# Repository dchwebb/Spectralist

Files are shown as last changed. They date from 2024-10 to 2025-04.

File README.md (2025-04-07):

# Spectralist

## Overview

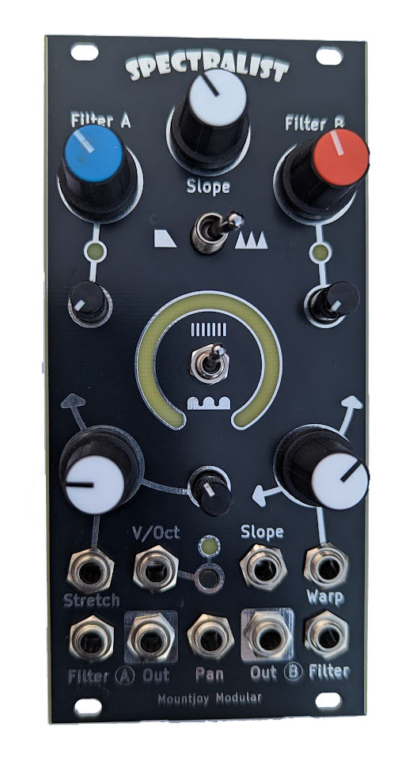
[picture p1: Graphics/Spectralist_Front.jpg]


Spectralist is an additive oscillator for Eurorack modular synthesisers. Up to 300 harmonics are output over two separate Odd and Even channels with a 'filter' offering a range of options for sculpting the harmonic spectrum of the output signals.

There are two harmonic modes - individual harmonics and sinusoidal waves of harmonics. In individual harmonic mode the spread controls adjust the spacing of the harmonics and the warp control either progressively bunches up or spreads out the harmonics. In the sinusoidal mode the spread controls increase the frequency of the 'waves' of harmonics.

The filter can be selected as a low pass filter with continuously adjustable slope or as a comb filter with adjustable tooth width and spread. In the comb filter mode the channel filter controls set the width between teeth and the slope sets the rise and fall times of the teeth. The individual channel filters controls can be adjusted with potentiometers or by CV with with trimmers to attenuate.

The pan CV input allows each channel to be smoothly panned between the two outputs. This can be used to mix the signals together in a mono setup, or used to dynamically shift the harmonics in the stereo field.

In the centre of the module is a ring of LEDs that give a visual representation of the harmonic spread and warp settings.

The module was designed in conjunction with musician Tal Shoshani who produced the following demonstration video:

IMAGE ALT TEXT HERE (https://www.youtube.com/watch?v=pN7oqAjkgNs)

## Technical

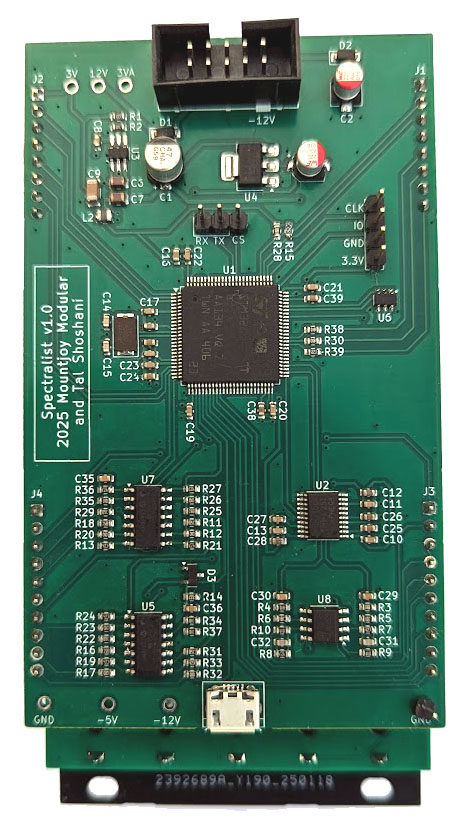
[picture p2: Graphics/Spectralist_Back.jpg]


The module is based around an STM32H723VGT microcontroller, clocked at 400MHz. A TI PCM5100APW 32 bit audio DAC is used for the two channel outputs.

A TL072 dual op-amps is used to amplify and filter the DAC output (and/or phase invert) the outputs from 3V to 9V peak-to-peak at maximum. Input CV signals are conditioned by MCP6004 op-amps.

A USB B micro port is available at the rear of the unit for software updgrades and configuration via a serial connection.

The animated 25 LED display is driven over I2C by a PCA9956B LED Driver and the SMD LEDs sit on a daughter board raising them to the level of the front panel.

[Components schematic](Hardware/Spectralist_Components.pdf)

[LED daughterboard schematic](Hardware/Spectralist_LED_Daughterboard.pdf)

[Controls schematic](Hardware/Spectralist_Controls.pdf)

## Power

Analog power is supplied via a 3.3V LDO regulator and digital power uses a TPS561201 switching power supply.

- +12V current draw: 139 mA
- -12V Current draw: 7 mA

## Errata

Panel Errata: Mode switch hole too large for subminiature switch
Filter type switch hole just too narrow
Harm_Warp_pot and Harm_Stretch_Pot wrong way round (fixed 1.1)

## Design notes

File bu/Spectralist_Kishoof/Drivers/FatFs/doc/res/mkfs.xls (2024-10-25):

Drive Size [sector] | ANY+SFD au = 0 |  |  | ANY+SFD au = 4096 |  |  | EXFAT+FAT32+SFD au = 0 |  |  | EXFAT+SFD au = 0 |  |  | FAT32+FAT+SFD au = 0 |  |  | FAT32+SFD au = 0 |  |  | FAT+SFD au = 0
 | Type | csize | n_clust | Type | csize | n_clust | Type | csize | n_clust | Type | csize | n_clust | Type | csize | n_clust | Type | csize | n_clust | Type | csize | n_clust
1024 | FAT12 | 1 | 987 | FAT12 | 8 | 123 |  |  |  |  |  |  | FAT12 | 1 | 987 |  |  |  | FAT12 | 1 | 987
1025 | FAT12 | 1 | 988 | FAT12 | 8 | 123 |  |  |  |  |  |  | FAT12 | 1 | 988 |  |  |  | FAT12 | 1 | 988
1026 | FAT12 | 1 | 989 | FAT12 | 8 | 124 |  |  |  |  |  |  | FAT12 | 1 | 989 |  |  |  | FAT12 | 1 | 989
1027 | FAT12 | 1 | 990 | FAT12 | 8 | 124 |  |  |  |  |  |  | FAT12 | 1 | 990 |  |  |  | FAT12 | 1 | 990
1028 | FAT12 | 1 | 991 | FAT12 | 8 | 124 |  |  |  |  |  |  | FAT12 | 1 | 991 |  |  |  | FAT12 | 1 | 991
1029 | FAT12 | 1 | 992 | FAT12 | 8 | 124 |  |  |  |  |  |  | FAT12 | 1 | 992 |  |  |  | FAT12 | 1 | 992
1030 | FAT12 | 1 | 993 | FAT12 | 8 | 124 |  |  |  |  |  |  | FAT12 | 1 | 993 |  |  |  | FAT12 | 1 | 993
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

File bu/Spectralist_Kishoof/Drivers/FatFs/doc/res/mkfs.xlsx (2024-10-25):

sz_vol [sector] | .fmt = ANY .au_size = 0 |  |  | .fmt = ANY .au_size = 4096 |  |  | .fmt = EXFAT+FAT32 .au_size = 0 |  |  | .fmt = EXFAT .au_size = 0 |  |  | .fmt = FAT32+FAT .au_size = 0 |  |  | .fmt = FAT32 .au_size = 0 |  |  | .fmt = FAT .au_size = 0
 | Type | csize | n_clust | Type | csize | n_clust | Type | csize | n_clust | Type | csize | n_clust | Type | csize | n_clust | Type | csize | n_clust | Type | csize | n_clust
1024 | FAT12 | 1 | 987 | FAT12 | 8 | 123 |  |  |  |  |  |  | FAT12 | 1 | 987 |  |  |  | FAT12 | 1 | 987
1025 | FAT12 | 1 | 988 | FAT12 | 8 | 123 |  |  |  |  |  |  | FAT12 | 1 | 988 |  |  |  | FAT12 | 1 | 988
1026 | FAT12 | 1 | 989 | FAT12 | 8 | 124 |  |  |  |  |  |  | FAT12 | 1 | 989 |  |  |  | FAT12 | 1 | 989
1027 | FAT12 | 1 | 990 | FAT12 | 8 | 124 |  |  |  |  |  |  | FAT12 | 1 | 990 |  |  |  | FAT12 | 1 | 990
1028 | FAT12 | 1 | 991 | FAT12 | 8 | 124 |  |  |  |  |  |  | FAT12 | 1 | 991 |  |  |  | FAT12 | 1 | 991
1029 | FAT12 | 1 | 992 | FAT12 | 8 | 124 |  |  |  |  |  |  | FAT12 | 1 | 992 |  |  |  | FAT12 | 1 | 992
1030 | FAT12 | 1 | 993 | FAT12 | 8 | 124 |  |  |  |  |  |  | FAT12 | 1 | 993 |  |  |  | FAT12 | 1 | 993
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

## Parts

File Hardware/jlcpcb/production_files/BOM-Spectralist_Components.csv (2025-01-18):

Comment | Designator | Footprint | LCSC
8MHz 20pF | Y1 | Crystal_SMD_Abracon_ABM3-2Pin_5.0x3.2mm | C115962
PCM5100APW | U2 | TSSOP-20_4.4x6.5mm_P0.65mm | C131154
100nF | C10,C11,C13,C17,C18,C19,C20,C21,C22,C23,C27,C36,C4,C8 | C_0603_1608Metric | C14663
100pF | C31,C32 | C_0603_1608Metric | C14858
1uF | C24,C3 | C_0603_1608Metric | C15849
2.2nF | C29,C30,C35 | C_0603_1608Metric | C1604
30pF | C14,C15 | C_0603_1608Metric | C1658
4.7uF | C16 | C_0603_1608Metric | C19666
10uF | C12,C28 | C_0603_1608Metric | C19702
1k | R3,R30,R38,R39,R4 | R_0603_1608Metric | C21190
100 | R10,R9 | R_0603_1608Metric | C22775
15k | R5,R6 | R_0603_1608Metric | C22809
1k6 | R15,R28 | R_0603_1608Metric | C22843
75k | R11,R16,R18,R22,R25,R29,R31 | R_0603_1608Metric | C23242
2.2uF | C25,C26,C38,C39 | C_0603_1608Metric | C23630
100k | R12,R17,R20,R23,R26,R32,R35 | R_0603_1608Metric | C25803
10k | R2,R34,R37 | R_0603_1608Metric | C25804
47k | R13,R19,R21,R24,R27,R33,R36,R7,R8 | R_0603_1608Metric | C25819
2k2 | R14 | R_0603_1608Metric | C4190
33k | R1 | R_0603_1608Metric | C4216
10uF | C6,C7 | C_0805_2012Metric | C440198
LT1117-3.3 | U4 | SOT-223-3_TabPin2 | C6186
TL072 | U8 | SOIC-8_3.9x4.9mm_P1.27mm | C6961
STM32H723VGTx | U1 | LQFP-100_14x14mm_P0.5mm | C730142
1N5819 | D1,D2 | D_SOD-123 | C8598
47uF | C9 | C_1206_3216Metric | C96123

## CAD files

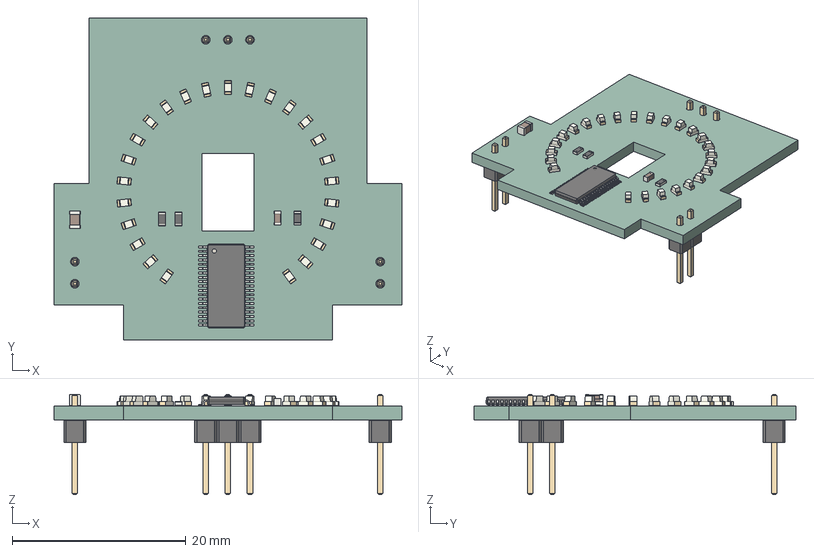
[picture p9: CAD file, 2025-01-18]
Hardware/Spectralist_LEDs.step
40.0 x 37.0 x 11.5 mm
LED_0603_1608Metric x 25
C_0805_2012Metric
R_0603_1608Metric x 3
TSSOP_38_44x97mm_P05mm
C_0603_1608Metric
PinHeader_1x02_P254mm_Vertical x 2
PinHeader_1x03_P254mm_Vertical
Spectralist_LEDs_PCB

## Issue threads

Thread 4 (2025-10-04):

Problem with firmware

tsanderakis, 2025-10-04:
Have started a Spectralist last week and for the moment I dont know which firmware is the right one.
I can talk to the STM with my Disco Board, but USB is not found, no output, just only LED No. 1 is on and thats all.
What can be wrong?
+-12V ok 5V ok 2x 3,3V ok

dchwebb, 2025-10-05:
I'm currently in Japan for a couple of weeks so have limited access to
GitHub etc. the latest firmware is here:
https://github.com/dchwebb/Spectralist/tree/main/Spectralist_H723/Debug

If you have tried that I am not sure why not working. When I am back happy
to work through some troubleshooting with you.

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

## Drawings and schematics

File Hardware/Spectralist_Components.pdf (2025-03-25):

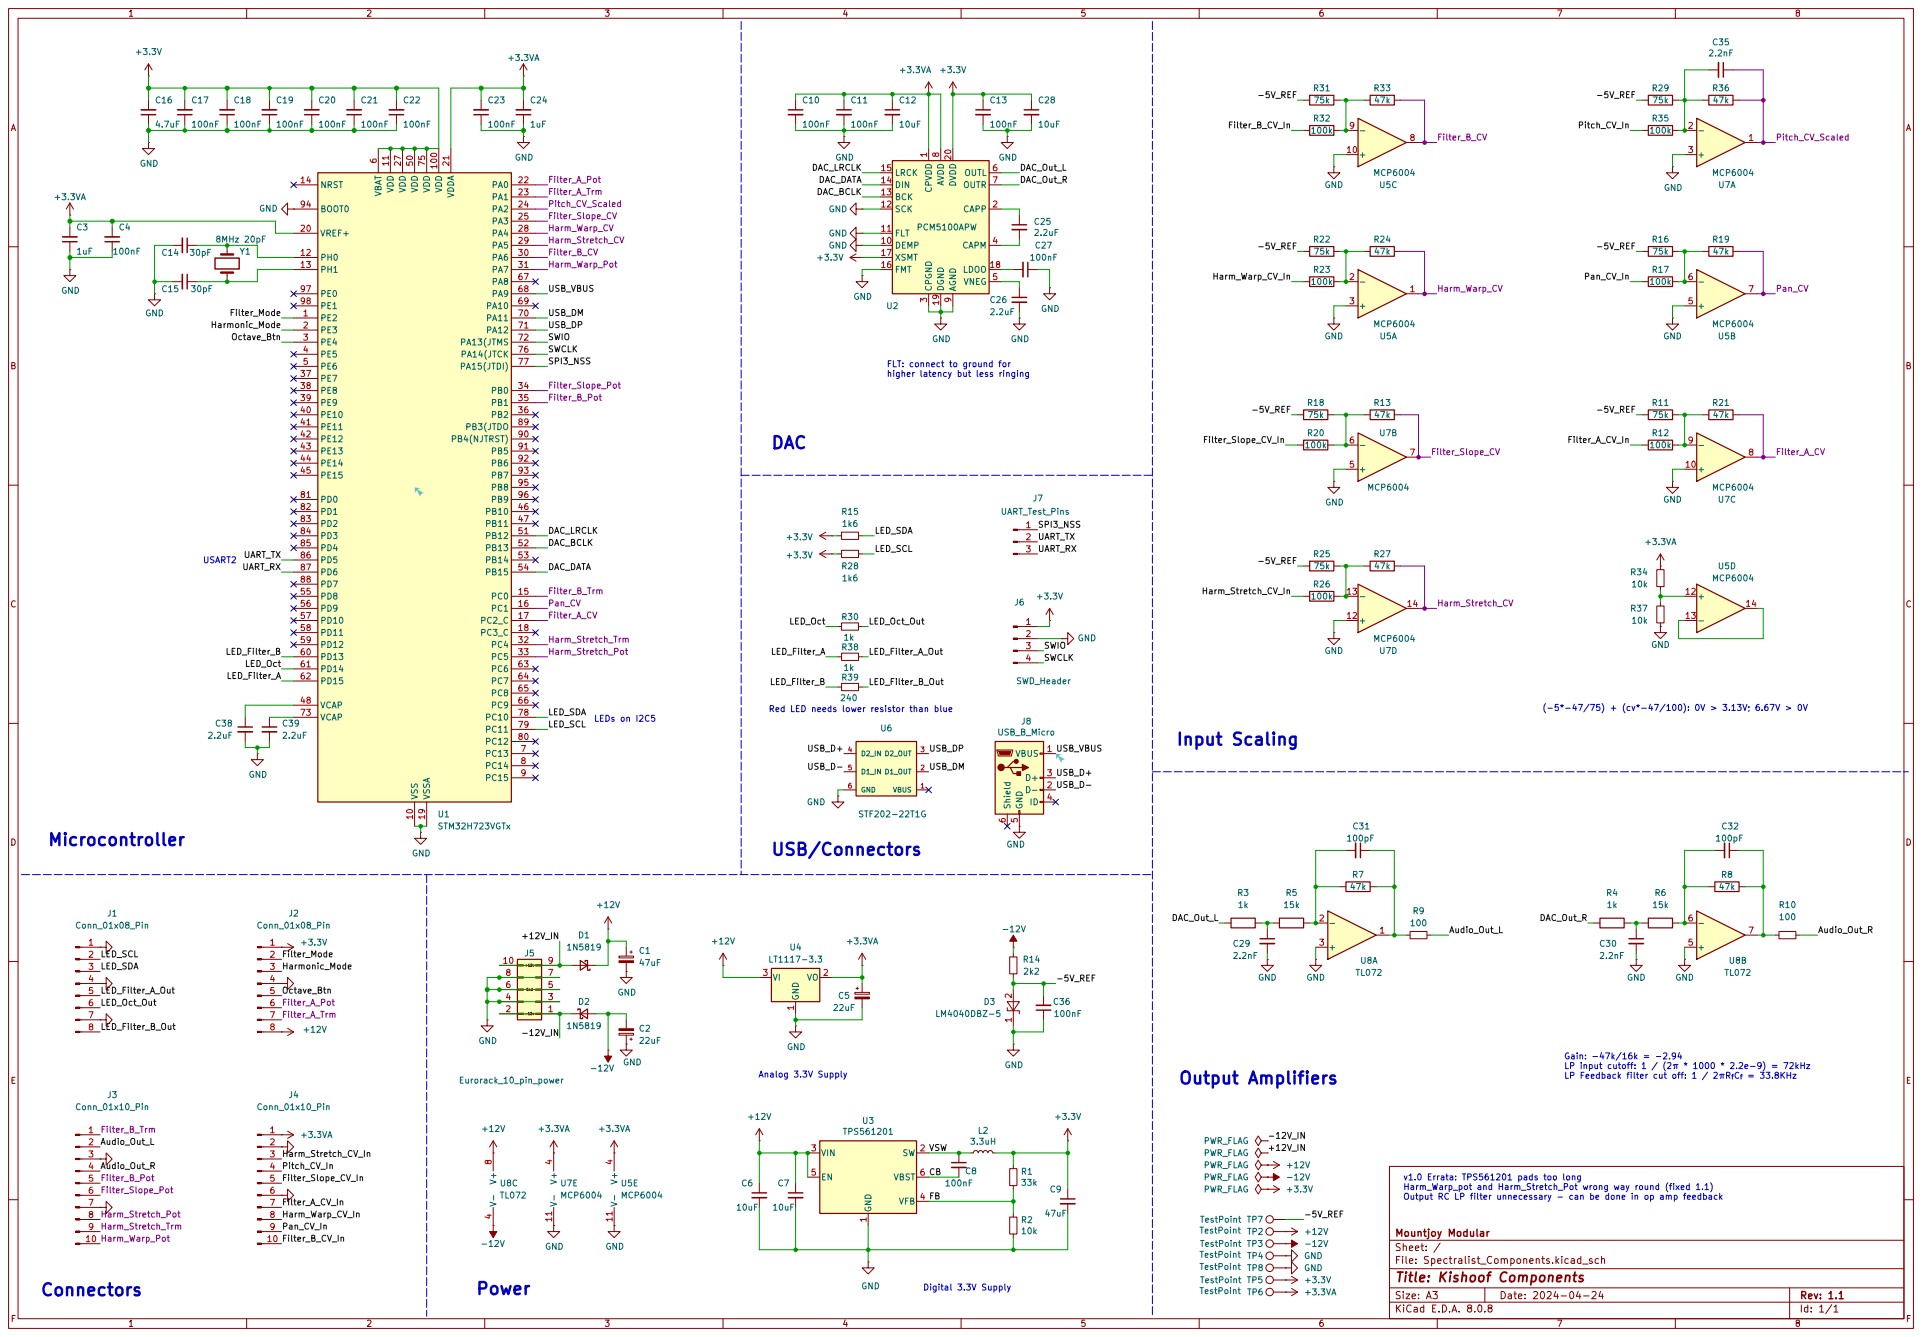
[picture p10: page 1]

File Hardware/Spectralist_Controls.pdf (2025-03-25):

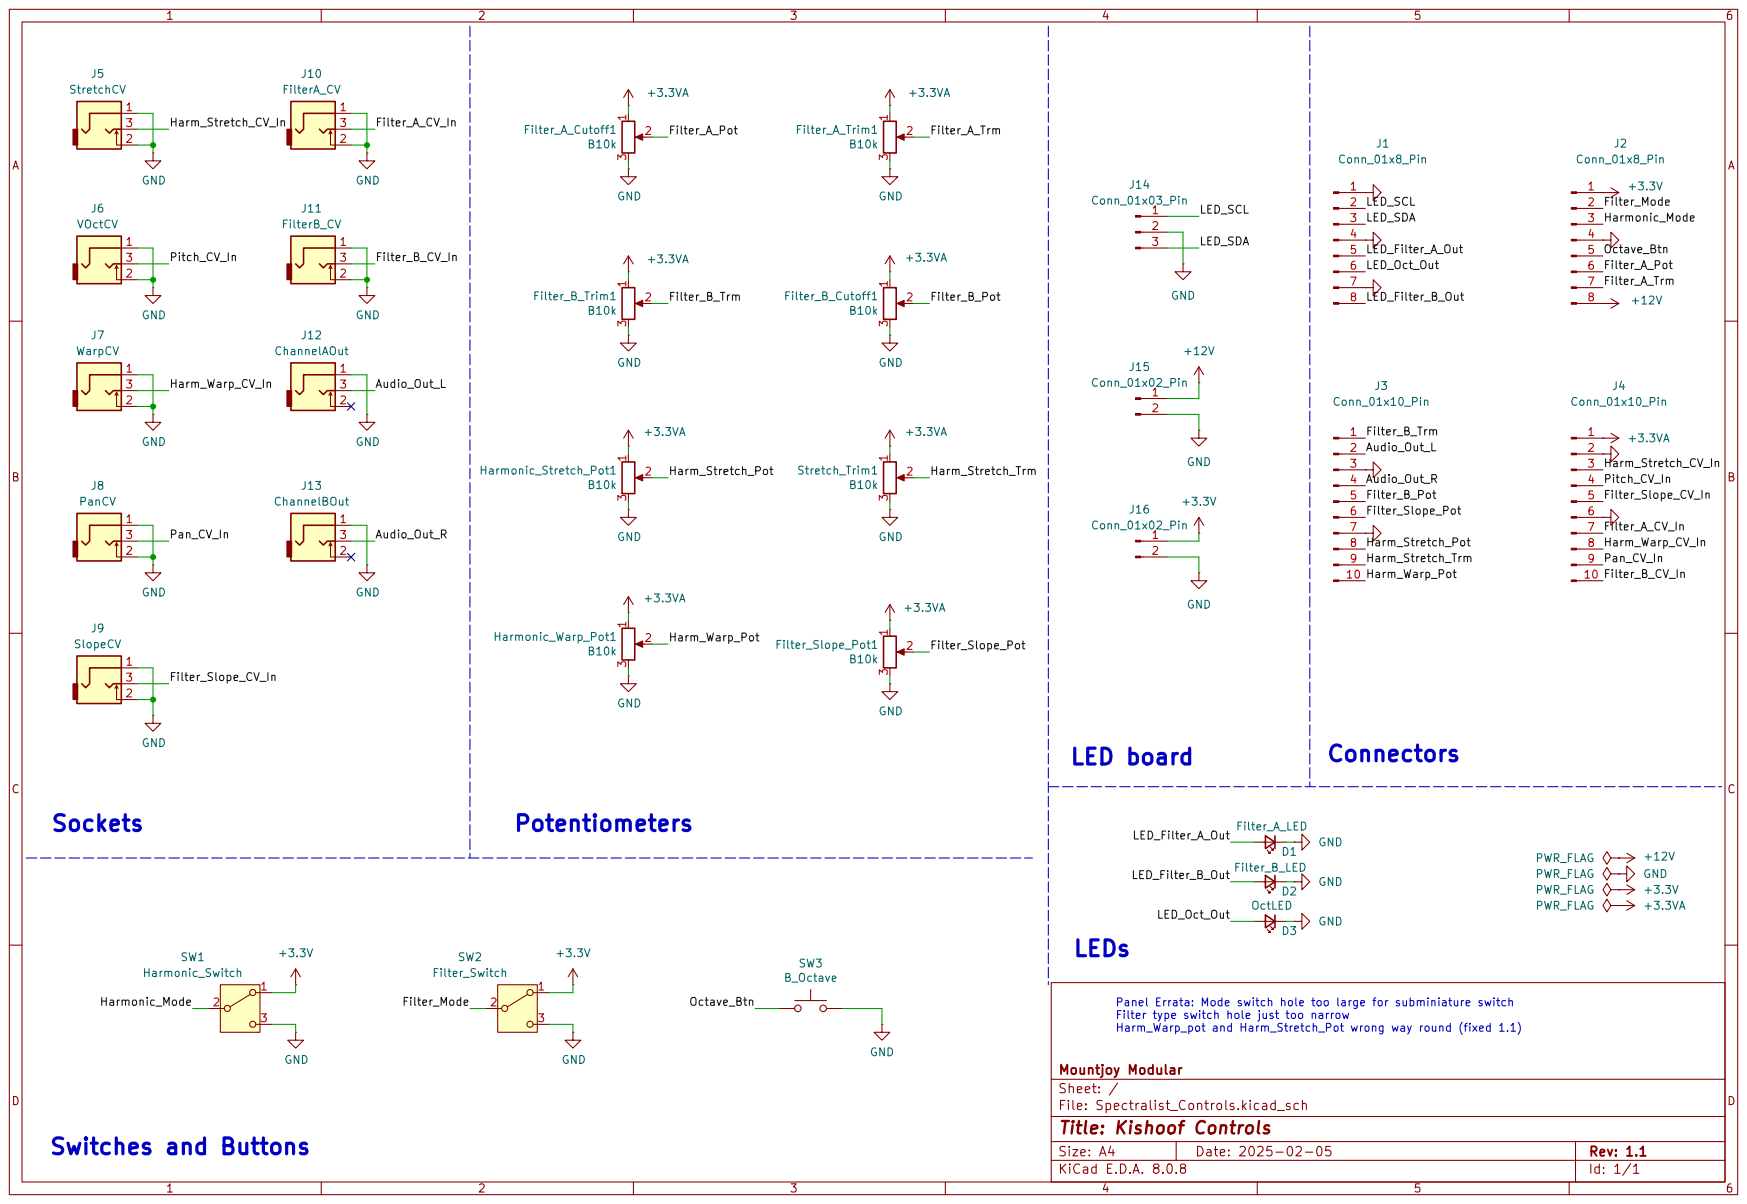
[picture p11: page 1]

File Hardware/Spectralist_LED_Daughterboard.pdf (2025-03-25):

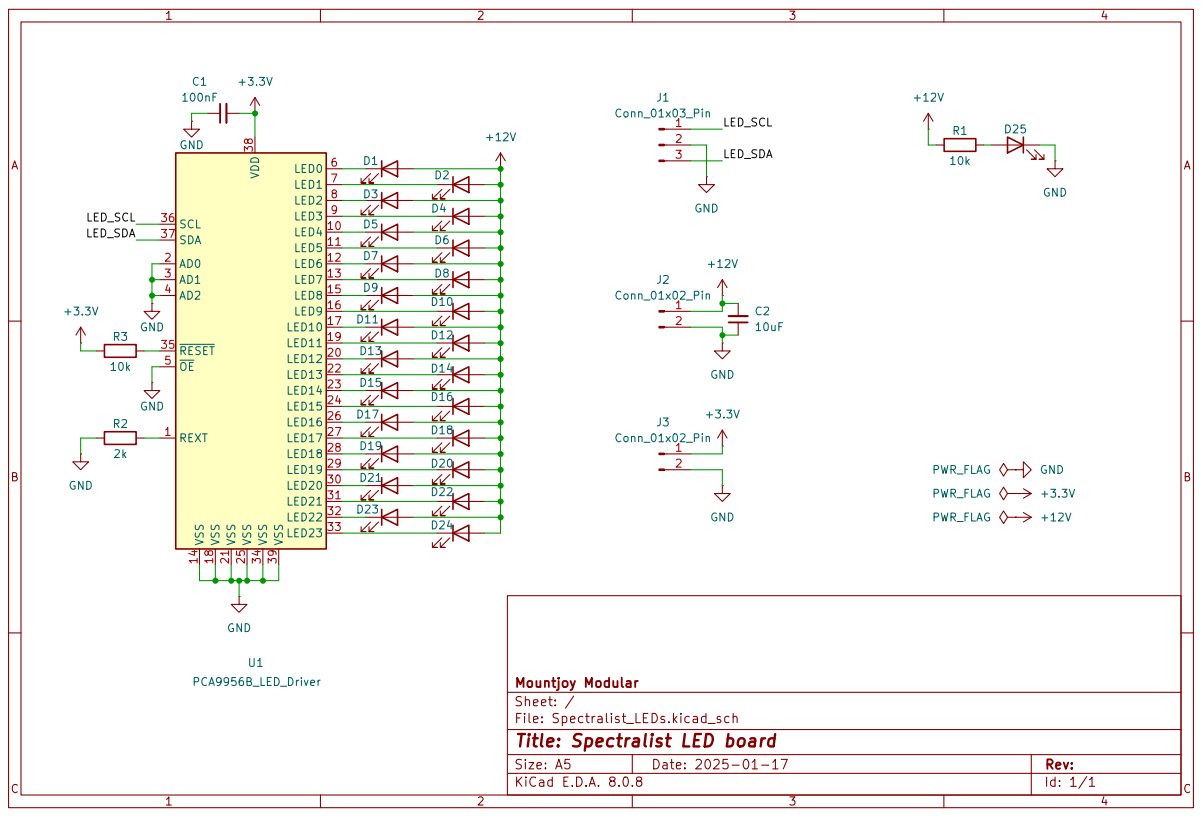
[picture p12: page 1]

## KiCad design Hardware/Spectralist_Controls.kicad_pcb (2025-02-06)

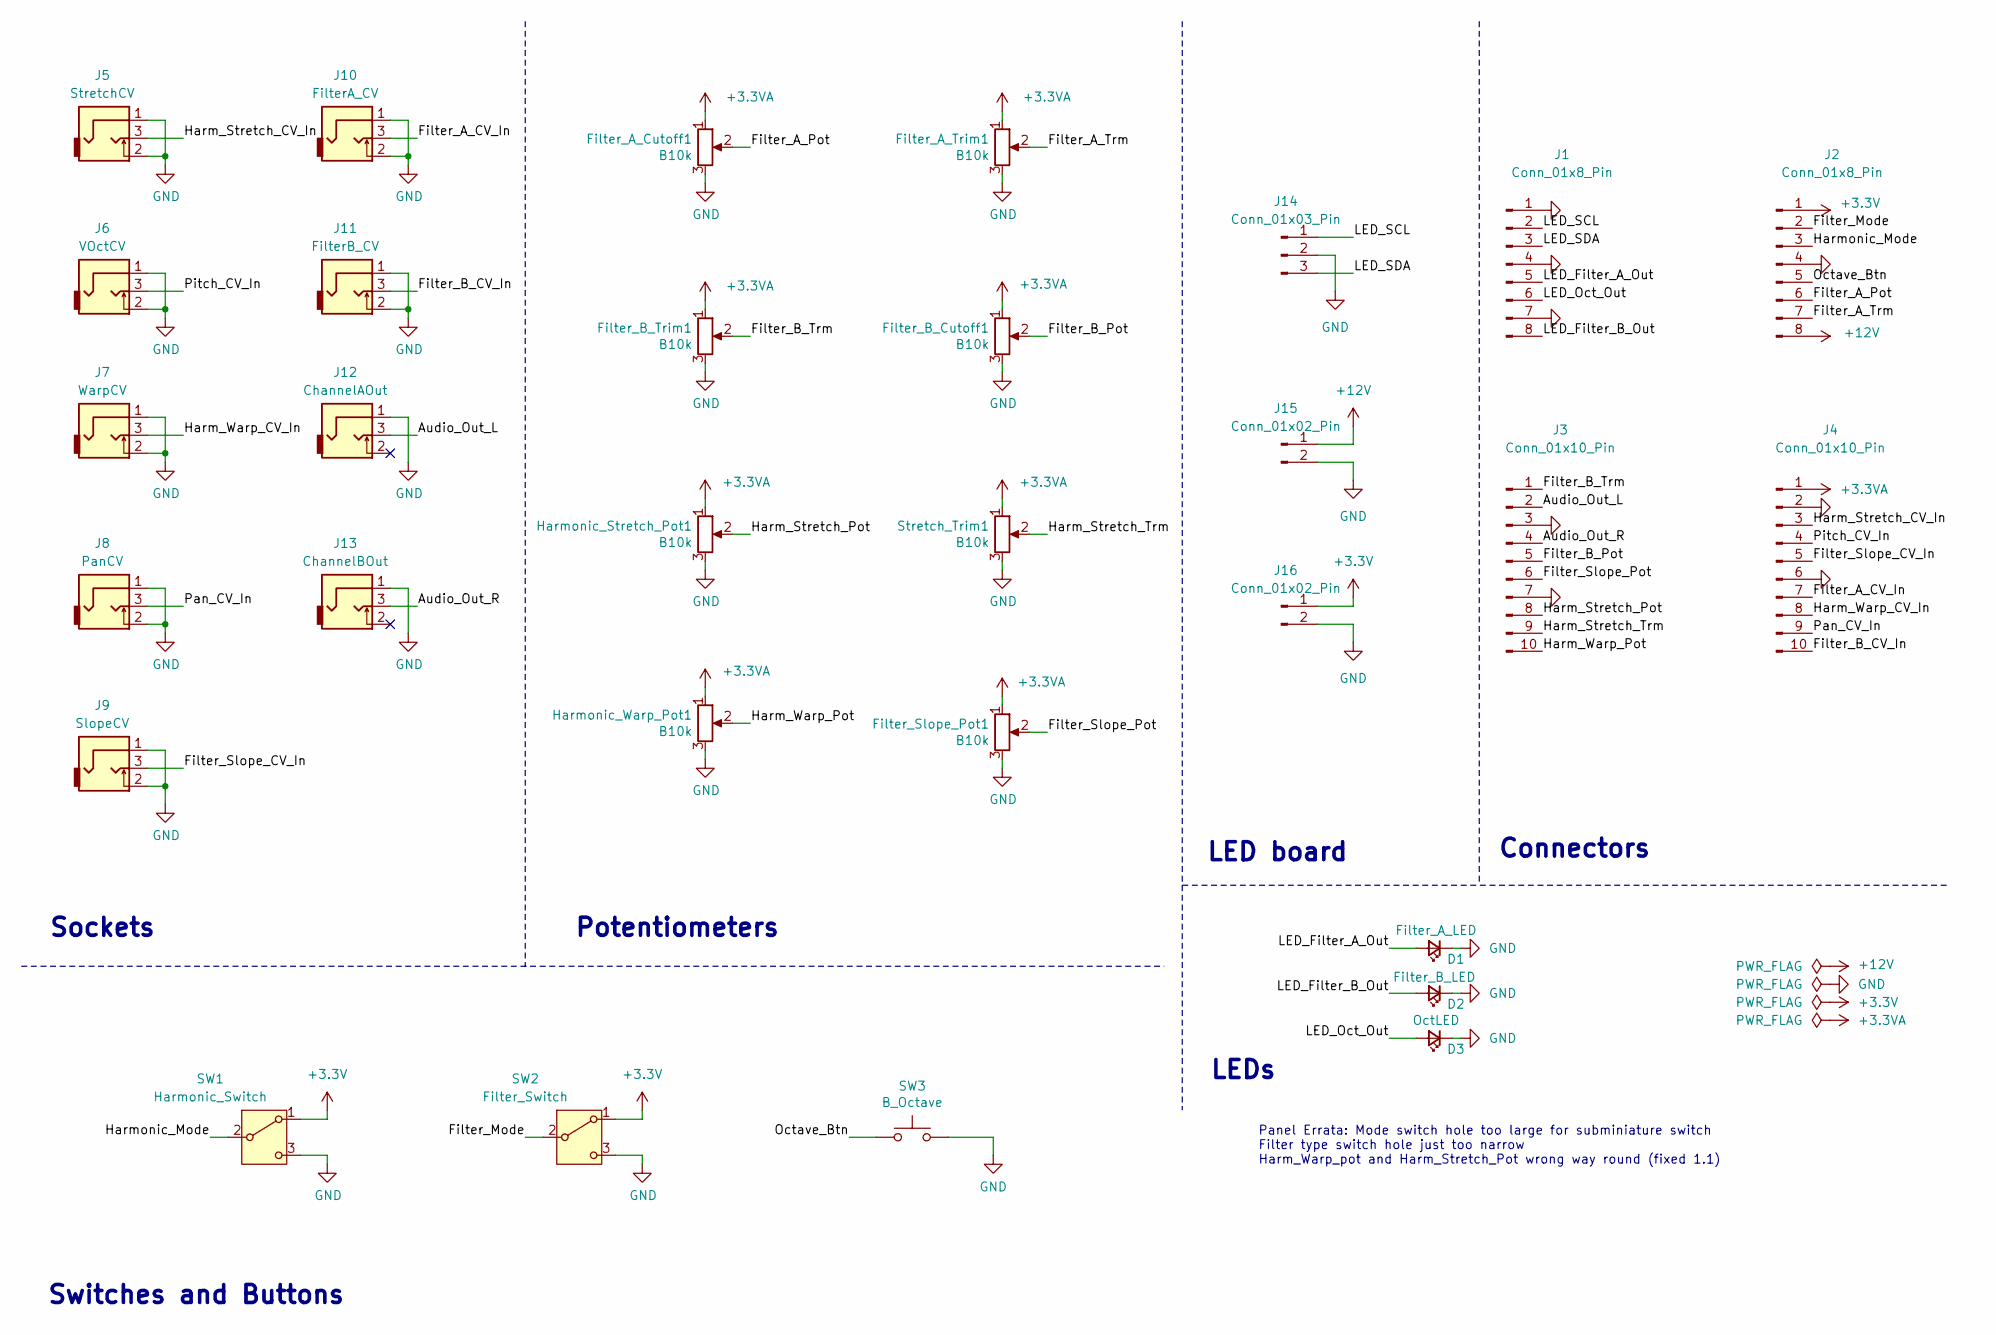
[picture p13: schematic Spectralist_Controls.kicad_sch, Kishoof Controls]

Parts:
D1: Filter_A_LED; LED_D3.0mm
D2: Filter_B_LED; LED_D3.0mm
D3: OctLED; LED_D3.0mm
Filter_A_Cutoff1: B10k; Alpha_9mm_Potentiometer_Aligned
Filter_A_Trim1: B10k; Alpha_9mm_Potentiometer_Aligned
Filter_B_Cutoff1: B10k; Alpha_9mm_Potentiometer_Aligned
Filter_B_Trim1: B10k; Alpha_9mm_Potentiometer_Aligned
Filter_Slope_Pot1: B10k; Alpha_9mm_Potentiometer_Aligned
Harmonic_Stretch_Pot1: B10k; Alpha_9mm_Potentiometer_Aligned
Harmonic_Warp_Pot1: B10k; Alpha_9mm_Potentiometer_Aligned
J1, J2: Conn_01x8_Pin; PinSocket_1x08_P2.54mm_Vertical
J3, J4: Conn_01x10_Pin; PinSocket_1x10_P2.54mm_Vertical
J5: StretchCV; THONKICONN_hole
J6: VOctCV; THONKICONN_hole
J7: WarpCV; THONKICONN_hole
J8: PanCV; THONKICONN_hole
J9: SlopeCV; THONKICONN_hole
J10: FilterA_CV; THONKICONN_hole
J11: FilterB_CV; THONKICONN_hole
J12: ChannelAOut; THONKICONN_hole
J13: ChannelBOut; THONKICONN_hole
J14: Conn_01x03_Pin; PinHeader_1x03_P2.54mm_Vertical
J15, J16: Conn_01x02_Pin; PinHeader_1x02_P2.54mm_Vertical
SW1: Harmonic_Switch; SPDT_SubMiniature_Aligned
SW2: Filter_Switch; SPDT_Miniature
SW3: B_Octave; SW_PUSH_6mm_aligned
Stretch_Trim1: B10k; Alpha_9mm_Potentiometer_Aligned

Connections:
+3.3V: J2.1, J16.1, SW1.1 (A), SW2.1 (A)
+3.3VA: Filter_A_Cutoff1.1, Filter_A_Trim1.1, Filter_B_Cutoff1.1, Filter_B_Trim1.1, Filter_Slope_Pot1.1, Harmonic_Stretch_Pot1.1, Harmonic_Warp_Pot1.1, J4.1, Stretch_Trim1.1
+12V: J2.8, J15.1
/Audio_Out_L: J3.2, J12.3
/Audio_Out_R: J3.4, J13.3
/Filter_A_CV_In: J4.7, J10.3
/Filter_A_Pot: Filter_A_Cutoff1.2, J2.6
/Filter_A_Trm: Filter_A_Trim1.2, J2.7
/Filter_B_CV_In: J4.10, J11.3
/Filter_B_Pot: Filter_B_Cutoff1.2, J3.5
/Filter_B_Trm: Filter_B_Trim1.2, J3.1
/Filter_Mode: J2.2, SW2.2 (B)
/Filter_Slope_CV_In: J4.5, J9.3
/Filter_Slope_Pot: Filter_Slope_Pot1.2, J3.6
/Harm_Stretch_CV_In: J4.3, J5.3
/Harm_Stretch_Pot: Harmonic_Stretch_Pot1.2, J3.8
/Harm_Stretch_Trm: J3.9, Stretch_Trim1.2
/Harm_Warp_CV_In: J4.8, J7.3
/Harm_Warp_Pot: Harmonic_Warp_Pot1.2, J3.10
/Harmonic_Mode: J2.3, SW1.2 (B)
/LED_Filter_A_Out: D1.2 (A), J1.5
/LED_Filter_B_Out: D2.2 (A), J1.8
/LED_Oct_Out: D3.2 (A), J1.6
/LED_SCL: J1.2, J14.1
/LED_SDA: J1.3, J14.3
/Octave_Btn: J2.5, SW3.1
/Pan_CV_In: J4.9, J8.3
/Pitch_CV_In: J4.4, J6.3
GND: D1.1 (K), D2.1 (K), D3.1 (K), Filter_A_Cutoff1.3, Filter_A_Trim1.3, Filter_B_Cutoff1.3, Filter_B_Trim1.3, Filter_Slope_Pot1.3, Harmonic_Stretch_Pot1.3, Harmonic_Warp_Pot1.3, J1.1, J1.4, J1.7, J2.4, J3.3, J3.7, J4.2, J4.6, J5.1, J5.2, J6.1, J6.2, J7.1, J7.2, J8.1, J8.2, J9.1, J9.2, J10.1, J10.2, J11.1, J11.2, J12.1, J13.1, J14.2, J15.2, J16.2, SW1.3 (C), SW2.3 (C), SW3.2, Stretch_Trim1.3

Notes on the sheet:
Sockets
Switches and Buttons
Panel Errata: Mode switch hole too large for subminiature switch Filter type switch hole just too narrow Harm_Warp_pot and Harm_Stretch_Pot wrong way round (fixed 1.1)
Connectors
LED board
LEDs
Potentiometers

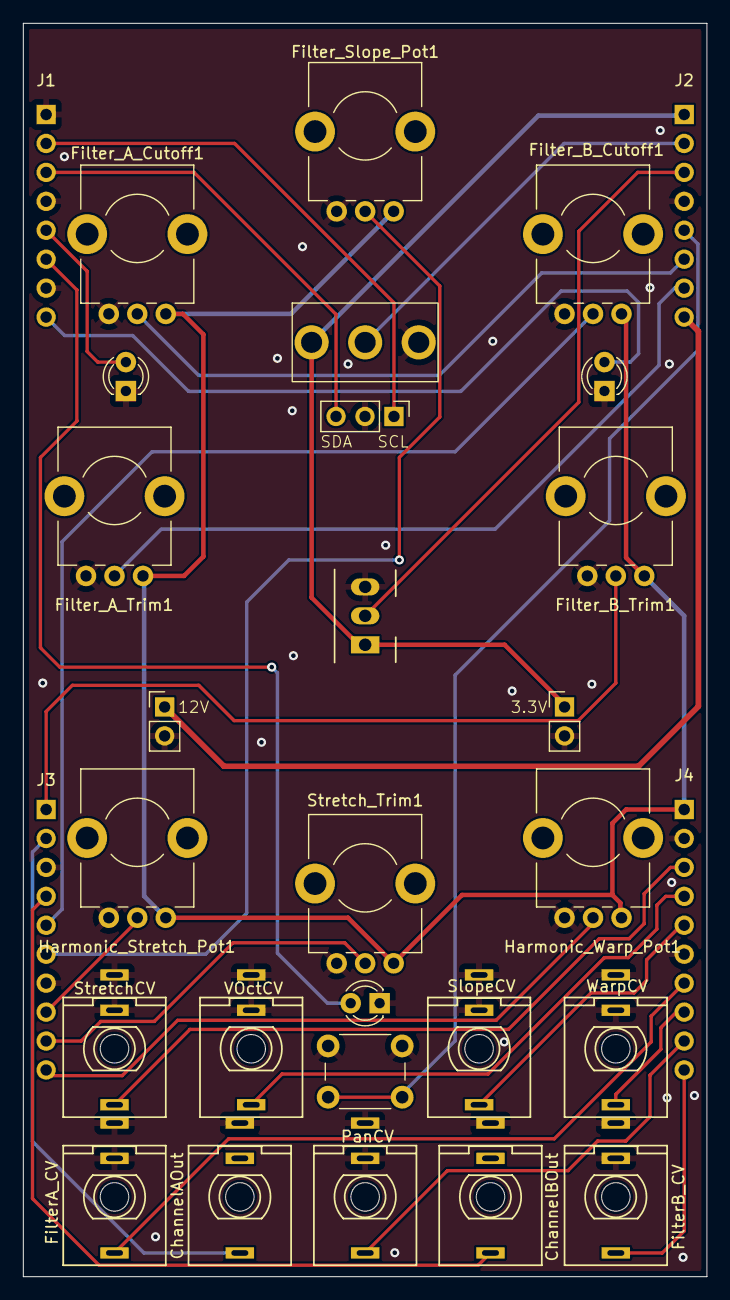
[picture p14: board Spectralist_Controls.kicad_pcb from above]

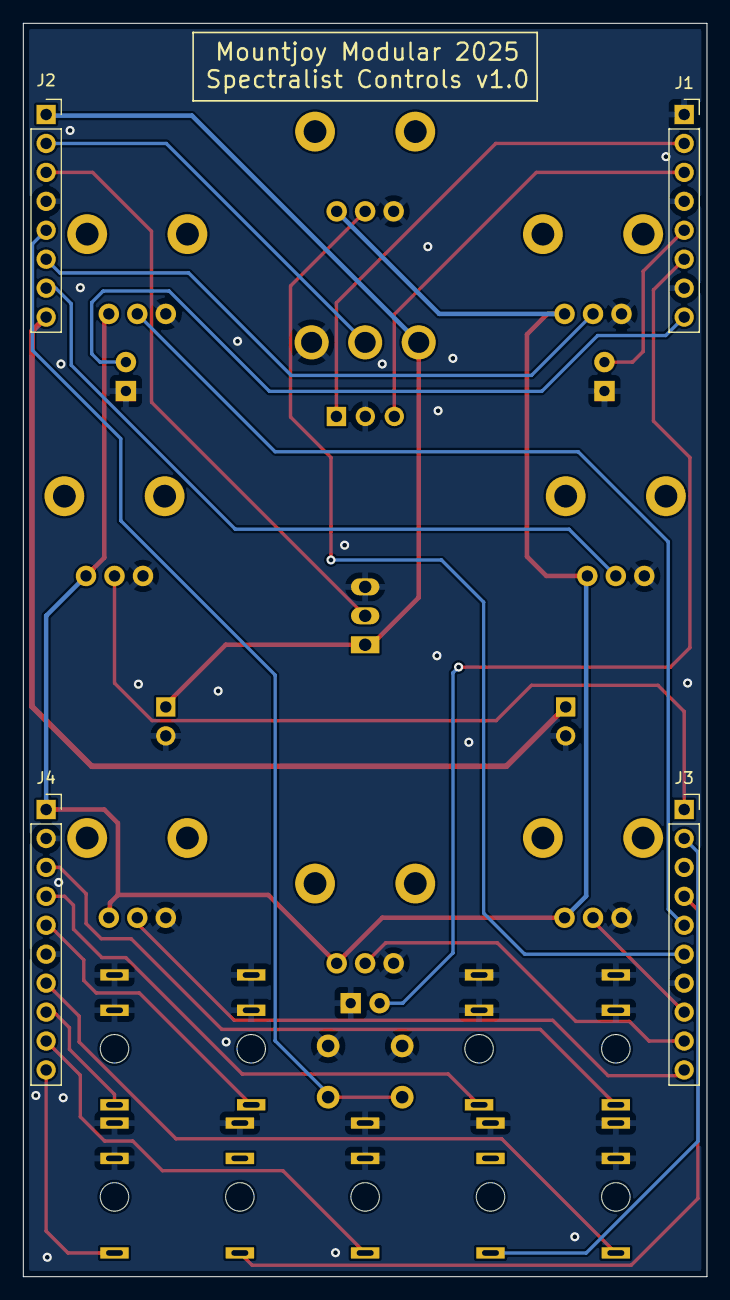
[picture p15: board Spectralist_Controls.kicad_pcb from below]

Board: 2 copper layers, 60.0 x 110.0 mm, 30 parts (4 on the bottom side), 29 nets.

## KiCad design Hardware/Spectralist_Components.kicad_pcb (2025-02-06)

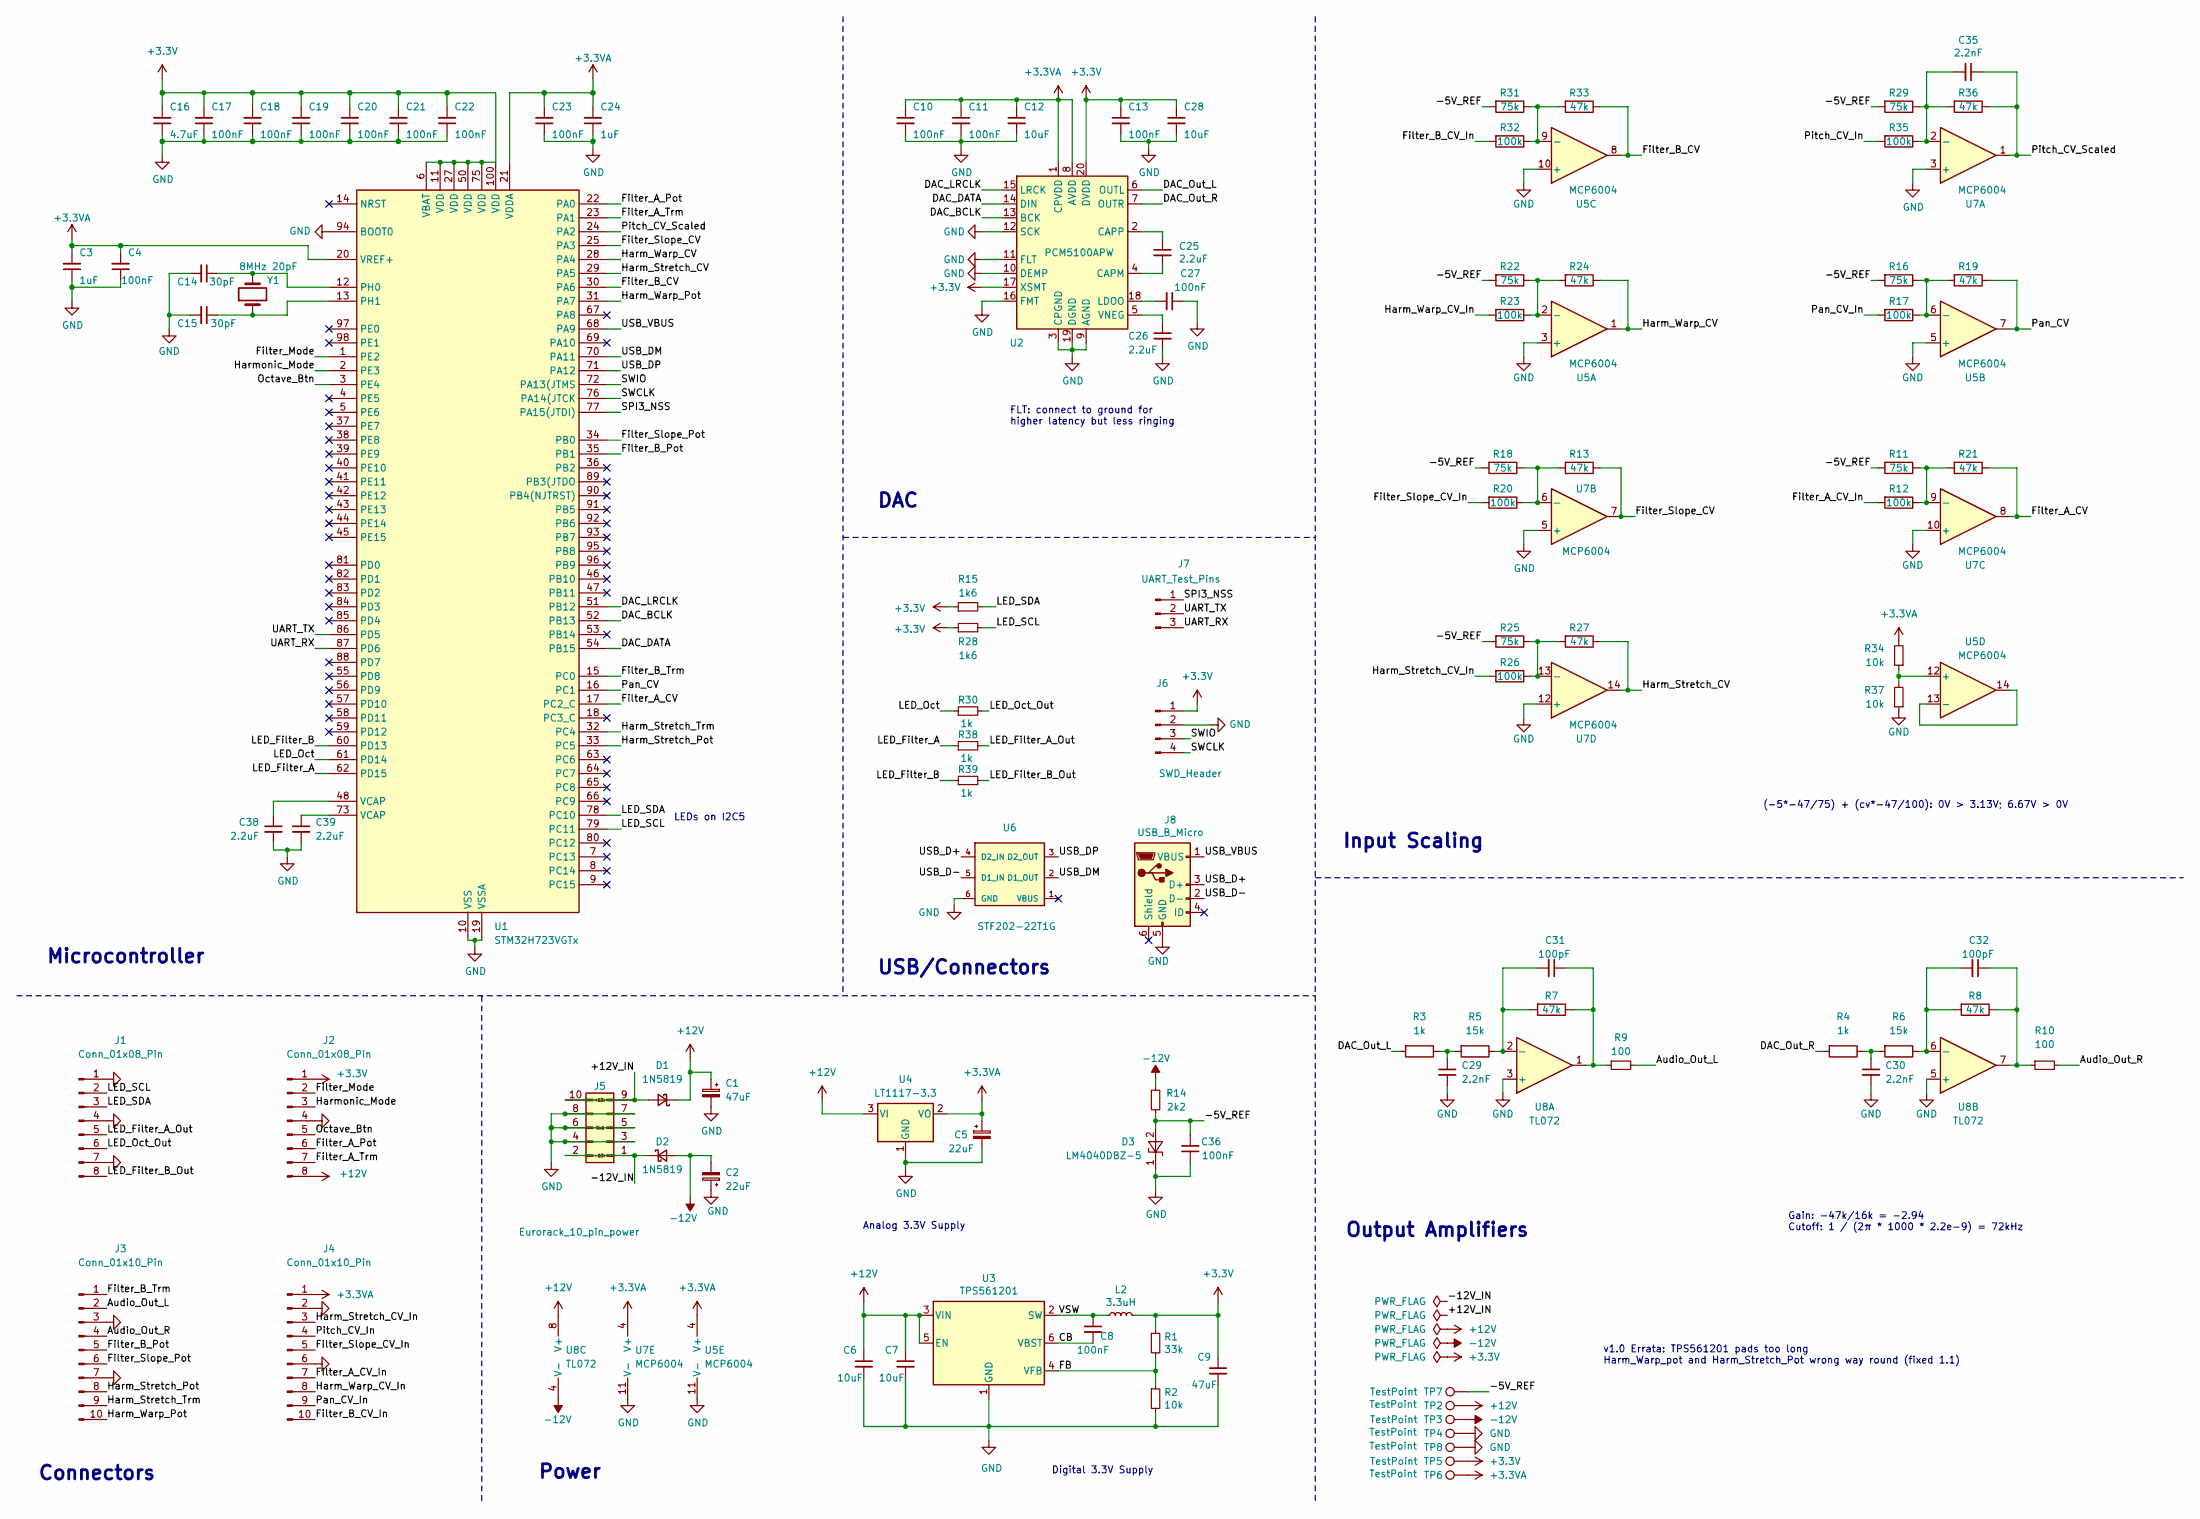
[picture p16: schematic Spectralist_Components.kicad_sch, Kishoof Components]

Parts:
C1: 47uF; CP_Elec_4x5.8
C2: 22uF; CP_Elec_4x5.8
C3, C24: 1uF; C_0603_1608Metric; Part_Number C15849
C4, C8, C10, C11, C13, C17, C18, C19, C20, C21, C22, C27, C36: 100nF; C_0603_1608Metric; Part_Number C14663
C5: 22uF; CP_Elec_4x5.8; Part_Number C134793
C6, C7: 10uF; C_0805_2012Metric; Part_Number C57112
C9: 47uF; C_1206_3216Metric; Part_Number C57112
C12, C28: 10uF; C_0603_1608Metric; Part_Number C15850
C14, C15: 30pF; C_0603_1608Metric; Part_Number C22397
C16: 4.7uF; C_0603_1608Metric; Part_Number C19666
C23: 100nF; C_0603_1608Metric; Part_Number C57112
C25, C26, C38, C39: 2.2uF; C_0603_1608Metric; Part_Number C23630
C29, C30, C35: 2.2nF; C_0603_1608Metric; Part_Number C1604
C31, C32: 100pF; C_0603_1608Metric; Part_Number C14858
D1, D2: 1N5819; D_SOD-123; Part_Number C8598
D3: LM4040DBZ-5; SOT-23; Part_Number C156291
J1, J2: Conn_01x08_Pin; PinHeader_1x08_P2.54mm_Vertical
J3, J4: Conn_01x10_Pin; PinHeader_1x10_P2.54mm_Vertical
J5: Eurorack_10_pin_power; Eurorack_10_pin_header
J6: SWD_Header; SWD_header
J7: UART_Test_Pins; PinHeader_1x03_P2.54mm_Vertical
J8: USB_B_Micro; USB_Micro-B_Amphenol
L2: 3.3uH; L_0806
R1: 33k; R_0603_1608Metric; Part_Number C25819
R2: 10k; R_0603_1608Metric; Part_Number C25804
R3, R4, R30, R38, R39: 1k; R_0603_1608Metric; Part_Number C4190
R5, R6: 15k; R_0603_1608Metric; Part_Number C25804
R7, R8, R13, R19, R21, R24, R27, R33, R36: 47k; R_0603_1608Metric; Part_Number C25819
R9, R10: 100; R_0603_1608Metric; Part_Number C4190
R11, R16, R18, R22, R25, R29, R31: 75k; R_0603_1608Metric; Part_Number C23242
R12, R17, R20, R23, R26, R32, R35: 100k; R_0603_1608Metric; Part_Number C23265
R14: 2k2; R_0603_1608Metric; Part_Number C4190
R15, R28: 1k6; R_0603_1608Metric; Part_Number C4190
R34, R37: 10k; R_0603_1608Metric; Part_Number C23162
TP2, TP3, TP4, TP5, TP6, TP7, TP8: TestPoint; 1.3mm_Test_Point
U1: STM32H723VGTx; LQFP-100_14x14mm_P0.5mm
U2: PCM5100APW; TSSOP-20_4.4x6.5mm_P0.65mm
U3: TPS561201; TSOT-23-6_HandSoldering
U4: LT1117-3.3; SOT-223-3_TabPin2
U5, U7: MCP6004; SO-14_3.9x8.65mm_P1.27mm
U6: STF202-22T1G
U8: TL072; SOIC-8_3.9x4.9mm_P1.27mm; Part_Number C6961
Y1: 8MHz 20pF; Crystal_SMD_Abracon_ABM3-2Pin_5.0x3.2mm; Part_Number C115962

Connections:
+3.3V: C9.1, C13.1, C16.2, C17.2, C18.2, C19.2, C20.2, C21.2, C22.2, C28.1, J2.1, J6.1, L2.2, R1.1, R15.1, R28.1, TP5.1, U1.6 (VBAT), U1.11 (VDD), U1.27 (VDD), U1.50 (VDD), U1.75 (VDD), U1.100 (VDD), U2.17 (XSMT), U2.20 (DVDD)
+3.3VA: C3.2, C4.2, C5.1, C10.1, C11.1, C12.1, C23.2, C24.2, J4.1, R34.2, TP6.1, U1.20 (VREF+), U1.21 (VDDA), U2.1 (CPVDD), U2.8 (AVDD), U4.2 (VO), U5.4 (V+), U7.4 (V+)
+12V: C1.1, C6.1, C7.1, D1.1 (K), J2.8, TP2.1, U3.3 (VIN), U3.5 (EN), U4.3 (VI), U8.8 (V+)
-12V: C2.2, D2.2 (A), R14.1, TP3.1, U8.4 (V-)
/+12V_IN: D1.2 (A), J5.9, J5.10
/-5V_REF: C36.2, D3.2 (A), R11.2, R14.2, R16.2, R18.2, R22.2, R25.2, R29.2, R31.2, TP7.1
/-12V_IN: D2.1 (K), J5.1, J5.2
/Audio_Out_L: J3.2, R9.2
/Audio_Out_R: J3.4, R10.2
/CB: C8.2, U3.6 (VBST)
/DAC_BCLK: U1.52 (PB13), U2.13 (BCK)
/DAC_DATA: U1.54 (PB15), U2.14 (DIN)
/DAC_LRCLK: U1.51 (PB12), U2.15 (LRCK)
/DAC_Out_L: R3.2, U2.6 (OUTL)
/DAC_Out_R: R4.2, U2.7 (OUTR)
/FB: R1.2, R2.1, U3.4 (VFB)
/Filter_A_CV: R21.1, U1.17 (PC2_C), U7.8
/Filter_A_CV_In: J4.7, R12.2
/Filter_A_Pot: J2.6, U1.22 (PA0)
/Filter_A_Trm: J2.7, U1.23 (PA1)
/Filter_B_CV: R33.1, U1.30 (PA6), U5.8
/Filter_B_CV_In: J4.10, R32.2
/Filter_B_Pot: J3.5, U1.35 (PB1)
/Filter_B_Trm: J3.1, U1.15 (PC0)
/Filter_Mode: J2.2, U1.1 (PE2)
/Filter_Slope_CV: R13.1, U1.25 (PA3), U7.7
/Filter_Slope_CV_In: J4.5, R20.2
/Filter_Slope_Pot: J3.6, U1.34 (PB0)
/Harm_Stretch_CV: R27.1, U1.29 (PA5), U7.14
/Harm_Stretch_CV_In: J4.3, R26.2
/Harm_Stretch_Pot: J3.8, U1.33 (PC5)
/Harm_Stretch_Trm: J3.9, U1.32 (PC4)
/Harm_Warp_CV: R24.1, U1.28 (PA4), U5.1
/Harm_Warp_CV_In: J4.8, R23.2
/Harm_Warp_Pot: J3.10, U1.31 (PA7)
/Harmonic_Mode: J2.3, U1.2 (PE3)
/LED_Filter_A: R38.1, U1.62 (PD15)
/LED_Filter_A_Out: J1.5, R38.2
/LED_Filter_B: R39.1, U1.60 (PD13)
/LED_Filter_B_Out: J1.8, R39.2
/LED_Oct: R30.1, U1.61 (PD14)
/LED_Oct_Out: J1.6, R30.2
/LED_SCL: J1.2, R28.2, U1.79 (PC11)
/LED_SDA: J1.3, R15.2, U1.78 (PC10)
/Octave_Btn: J2.5, U1.3 (PE4)
/Pan_CV: R19.1, U1.16 (PC1), U5.7
/Pan_CV_In: J4.9, R17.2
/Pitch_CV_In: J4.4, R35.2
/Pitch_CV_Scaled: C35.1, R36.1, U1.24 (PA2), U7.1
/SPI3_NSS: J7.1, U1.77 (PA15(JTDI))
/SWCLK: J6.4, U1.76 (PA14(JTCK)
/SWIO: J6.3, U1.72 (PA13(JTMS)
/UART_RX: J7.3, U1.87 (PD6)
/UART_TX: J7.2, U1.86 (PD5)
/USB_D+: J8.3 (D+), U6.4 (D2_IN)
/USB_D-: J8.2 (D-), U6.5 (D1_IN)
/USB_DM: U1.70 (PA11), U6.2 (D1_OUT)
/USB_DP: U1.71 (PA12), U6.3 (D2_OUT)
/USB_VBUS: J8.1 (VBUS), U1.68 (PA9)
/VSW: C8.1, L2.1, U3.2 (SW)
GND: C1.2, C2.1, C3.1, C4.1, C5.2, C6.2, C7.2, C9.2, C10.2, C11.2, C12.2, C13.2, C14.2, C15.2, C16.1, C17.1, C18.1, C19.1, C20.1, C21.1, C22.1, C23.1, C24.1, C26.2, C27.1, C28.2, C29.2, C30.2, C36.1, C38.2, C39.2, D3.1 (K), J1.1, J1.4, J1.7, J2.4, J3.3, J3.7, J4.2, J4.6, J5.3, J5.4, J5.5, J5.6, J5.7, J5.8, J6.2, J8.5 (GND), R2.2, R37.1, TP4.1, TP8.1, U1.10 (VSS), U1.19 (VSSA), U1.26 (VSS), U1.49 (VSS), U1.74 (VSS), U1.94 (BOOT0), U1.99 (VSS), U2.3 (CPGND), U2.9 (AGND), U2.10 (DEMP), U2.11 (FLT), U2.12 (SCK), U2.16 (FMT), U2.19 (DGND), U3.1 (GND), U4.1 (GND), U5.3 (+), U5.5 (+), U5.10 (+), U5.11 (V-), U6.6 (GND), U7.3 (+), U7.5 (+), U7.10 (+), U7.11 (V-), U7.12 (+), U8.3 (+), U8.5 (+)
unnamed: C29.1, R3.1, R5.2
unnamed: C30.1, R4.1, R6.2
unnamed: C31.1, R7.1, R9.1, U8.1
unnamed: C32.1, R8.1, R10.1, U8.7
unnamed: C38.1, U1.48 (VCAP)
unnamed: C39.1, U1.73 (VCAP)
unnamed: C14.1, U1.12 (PH0), Y1.2
unnamed: C15.1, U1.13 (PH1), Y1.1
unnamed: C25.2, U2.4 (CAPM)
unnamed: C25.1, U2.2 (CAPP)
unnamed: C27.2, U2.18 (LDOO)
unnamed: C26.1, U2.5 (VNEG)
unnamed: R22.1, R23.1, R24.2, U5.2 (-)
unnamed: R16.1, R17.1, R19.2, U5.6 (-)
unnamed: R31.1, R32.1, R33.2, U5.9 (-)
unnamed: R34.1, R37.2, U5.12 (+)
unnamed: U5.13 (-), U5.14
unnamed: C35.2, R29.1, R35.1, R36.2, U7.2 (-)
unnamed: R13.2, R18.1, R20.1, U7.6 (-)
unnamed: R11.1, R12.1, R21.2, U7.9 (-)
unnamed: R25.1, R26.1, R27.2, U7.13 (-)
unnamed: C31.2, R5.1, R7.2, U8.2 (-)
unnamed: C32.2, R6.1, R8.2, U8.6 (-)

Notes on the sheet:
DAC
Gain: -47k/16k = -2.94 Cutoff: 1 / (2π * 1000 * 2.2e-9) = 72kHz
Connectors
FLT: connect to ground for higher latency but less ringing
Digital 3.3V Supply
USB/Connectors
LEDs on I2C5
(-5*-47/75) + (cv*-47/100): 0V > 3.13V; 6.67V > 0V
v1.0 Errata: TPS561201 pads too long Harm_Warp_pot and Harm_Stretch_Pot wrong way round (fixed 1.1)
Input Scaling
Output Amplifiers
Power
Analog 3.3V Supply
Microcontroller

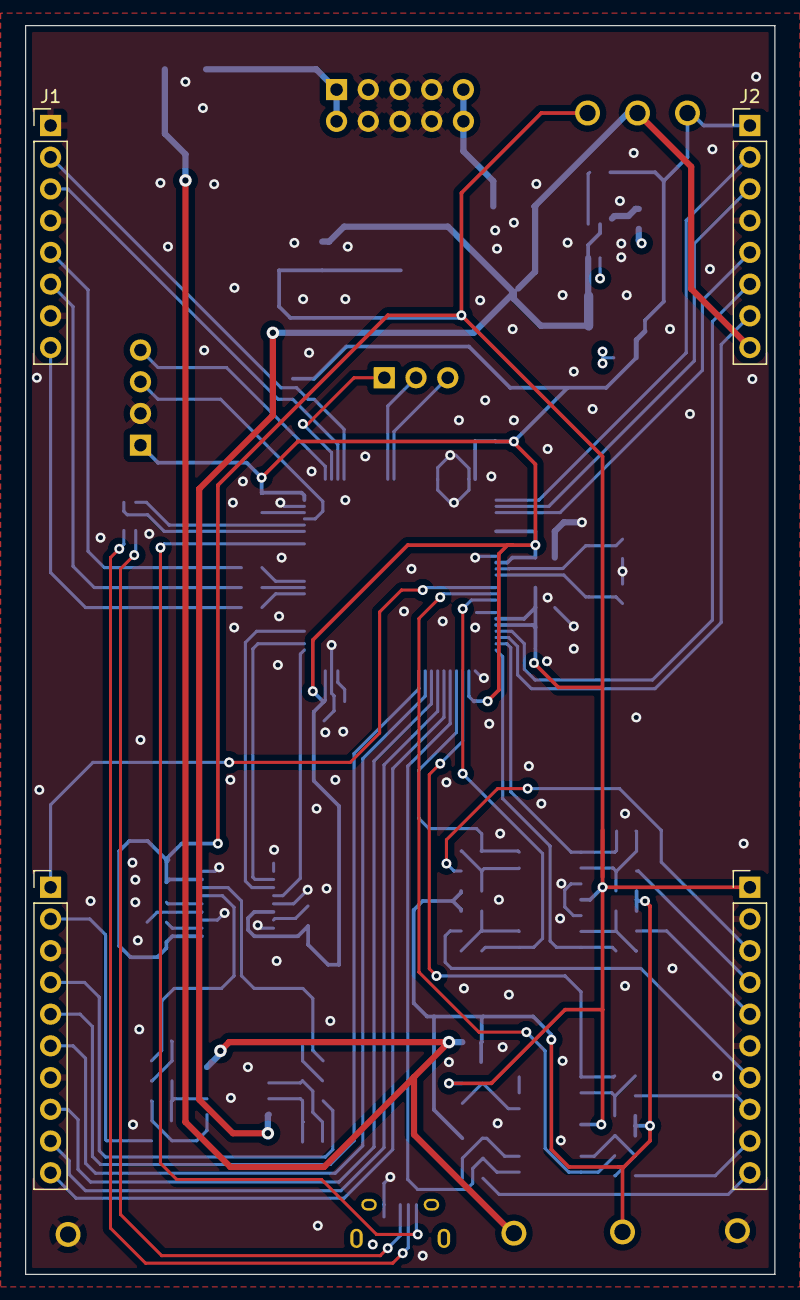
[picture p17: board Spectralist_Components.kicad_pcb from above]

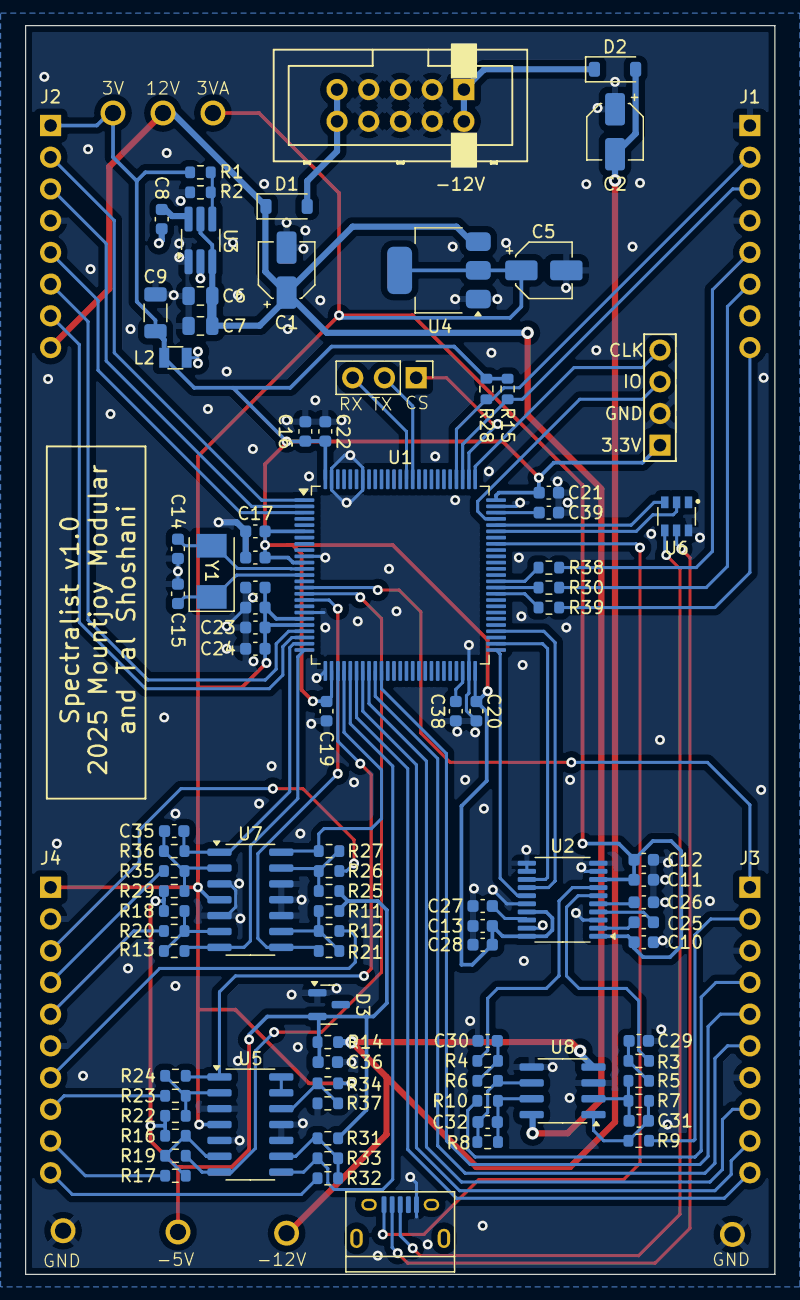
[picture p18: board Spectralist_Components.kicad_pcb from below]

Board: 4 copper layers, 60.0 x 100.0 mm, 103 parts (99 on the bottom side), 84 nets.

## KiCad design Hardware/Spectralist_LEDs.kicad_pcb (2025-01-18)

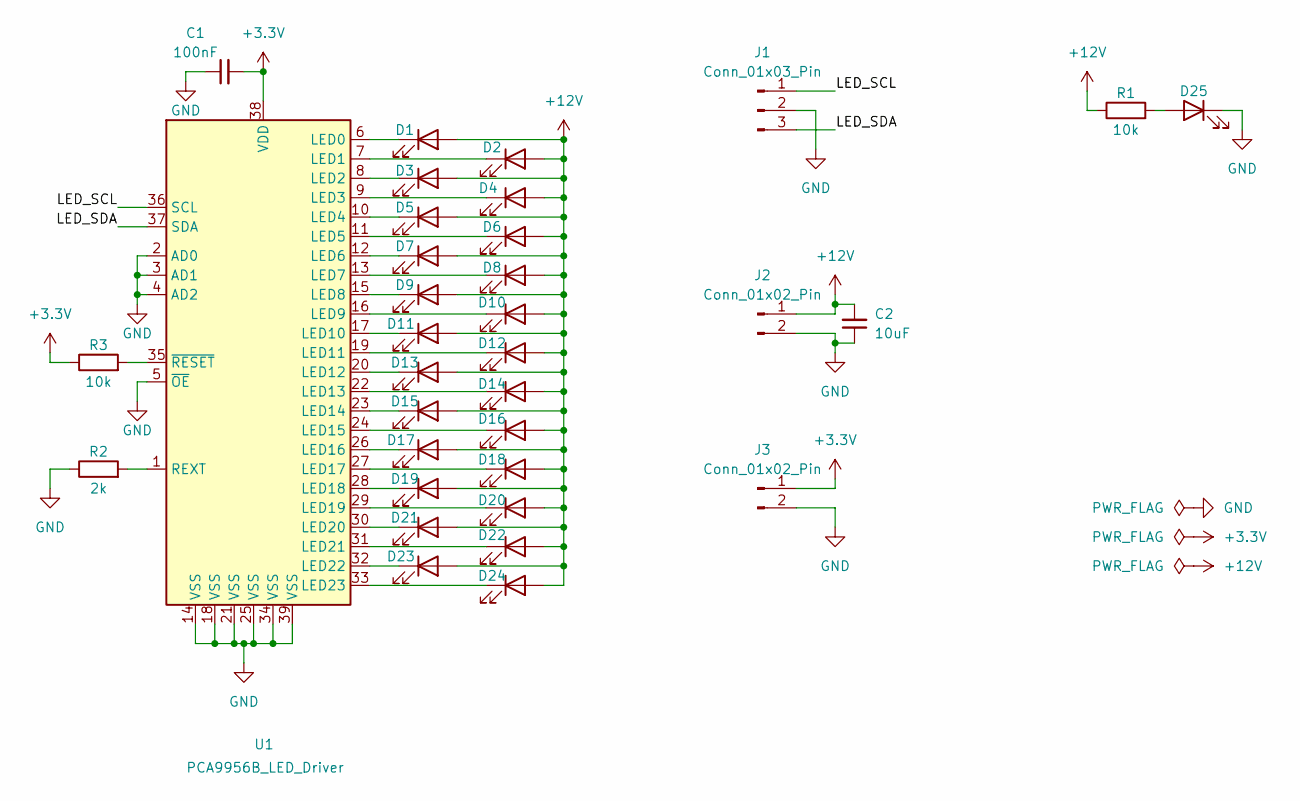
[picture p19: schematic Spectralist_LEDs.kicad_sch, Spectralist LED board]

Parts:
C1: 100nF; C_0603_1608Metric; Part_Number C14663
C2: 10uF; C_0805_2012Metric; Part_Number C14663
D1, D2, D3, D4, D5, D6, D7, D8, D9, D10, D11, D12, D13, D14, D15, D16, D17, D18, D19, D20, D21, D22, D23, D24, D25: LED; LED_0603_1608Metric
J1: Conn_01x03_Pin; PinHeader_1x03_P2.54mm_Vertical
J2, J3: Conn_01x02_Pin; PinHeader_1x02_P2.54mm_Vertical
R1, R3: 10k; R_0603_1608Metric
R2: 2k; R_0603_1608Metric
U1: PCA9956B_LED_Driver; HTSSOP-38_4.4x9.7mm_P0.5mm

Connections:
+3.3V: C1.2, J3.1, R3.1, U1.38 (VDD)
+12V: C2.2, D1.2 (A), D2.2 (A), D3.2 (A), D4.2 (A), D5.2 (A), D6.2 (A), D7.2 (A), D8.2 (A), D9.2 (A), D10.2 (A), D11.2 (A), D12.2 (A), D13.2 (A), D14.2 (A), D15.2 (A), D16.2 (A), D17.2 (A), D18.2 (A), D19.2 (A), D20.2 (A), D21.2 (A), D22.2 (A), D23.2 (A), D24.2 (A), J2.1, R1.1
/LED_SCL: J1.1, U1.36 (SCL)
/LED_SDA: J1.3, U1.37 (SDA)
GND: C1.1, C2.1, D25.1 (K), J1.2, J2.2, J3.2, R2.1, U1.2 (AD0), U1.3 (AD1), U1.4 (AD2), U1.5 (~OE), U1.14 (VSS), U1.18 (VSS), U1.21 (VSS), U1.25 (VSS), U1.34 (VSS), U1.39 (VSS)
unnamed: D1.1 (K), U1.6 (LED0)
unnamed: D2.1 (K), U1.7 (LED1)
unnamed: D3.1 (K), U1.8 (LED2)
unnamed: D4.1 (K), U1.9 (LED3)
unnamed: D5.1 (K), U1.10 (LED4)
unnamed: D6.1 (K), U1.11 (LED5)
unnamed: D7.1 (K), U1.12 (LED6)
unnamed: D8.1 (K), U1.13 (LED7)
unnamed: D9.1 (K), U1.15 (LED8)
unnamed: D10.1 (K), U1.16 (LED9)
unnamed: D11.1 (K), U1.17 (LED10)
unnamed: D12.1 (K), U1.19 (LED11)
unnamed: D13.1 (K), U1.20 (LED12)
unnamed: D14.1 (K), U1.22 (LED13)
unnamed: D15.1 (K), U1.23 (LED14)
unnamed: D16.1 (K), U1.24 (LED15)
unnamed: D17.1 (K), U1.26 (LED16)
unnamed: D18.1 (K), U1.27 (LED17)
unnamed: D19.1 (K), U1.28 (LED18)
unnamed: D20.1 (K), U1.29 (LED19)
unnamed: D21.1 (K), U1.30 (LED20)
unnamed: D22.1 (K), U1.31 (LED21)
unnamed: D23.1 (K), U1.32 (LED22)
unnamed: D24.1 (K), U1.33 (LED23)
unnamed: D25.2 (A), R1.2
unnamed: R2.2, U1.1 (REXT)
unnamed: R3.2, U1.35 (~RESET)

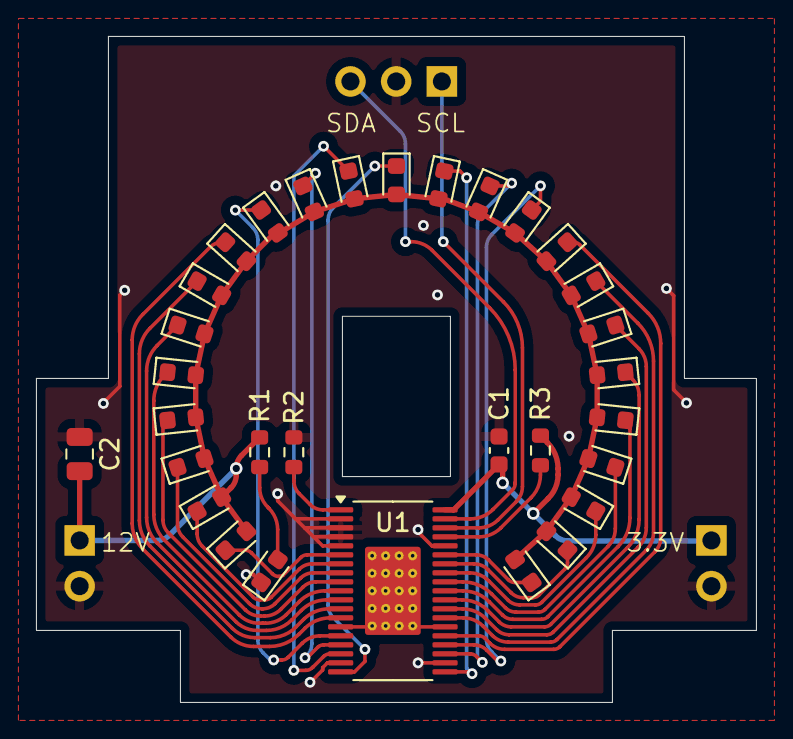
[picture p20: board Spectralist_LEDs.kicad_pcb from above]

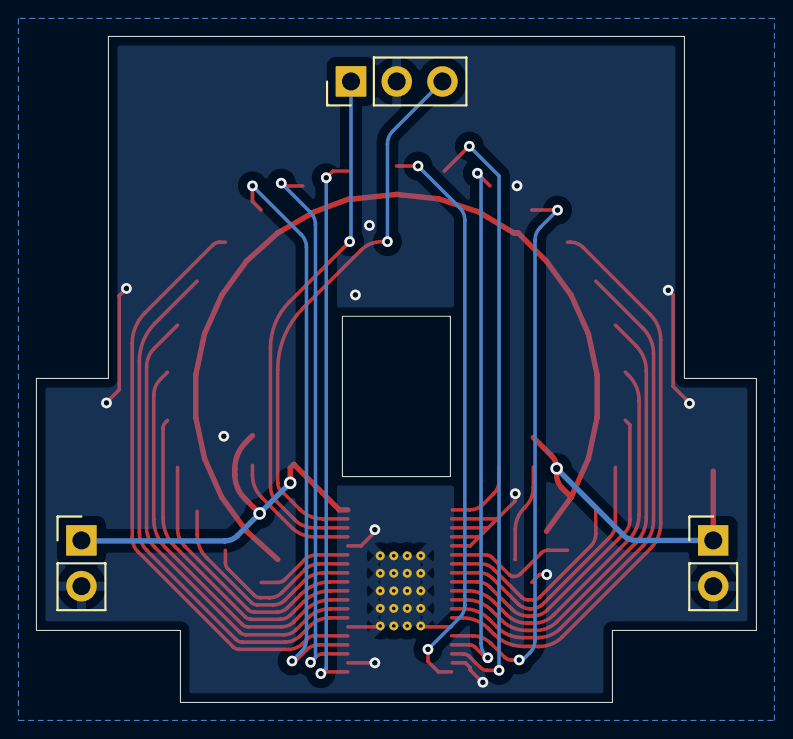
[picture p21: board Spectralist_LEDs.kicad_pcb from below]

Board: 2 copper layers, 40.0 x 37.0 mm, 34 parts (3 on the bottom side), 32 nets.

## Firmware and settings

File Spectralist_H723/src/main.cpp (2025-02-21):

#include "initialisation.h"
#include "CDCHandler.h"
#include "USB.h"
#include "configManager.h"
#include "ledManager.h"
#include "Calib.h"
#include "Additive.h"

volatile uint32_t SysTickVal;
extern uint32_t SystemCoreClock;

volatile ADCValues __attribute__((section (".dma_buffer"))) adc;	// Store adc buffer in non-cached memory area

// Initialise configurable globals here to ensure objects exist before config initialisation runs
Additive additive;
Calib calib;

Config config{&calib.configSaver, &additive.configSaver};			// Construct config handler with list of configSavers

extern "C" {
#include "interrupts.h"
}

bool USBDebug = false;

int main(void) {

	InitClocks();					// Configure the clock and PLL
	InitHardware();
	config.RestoreConfig();
	usb.Init(false);
	ledManager.Init();
	InitI2S();						// Initialise I2S which will start main sample interrupts

	while (1) {
		usb.cdc.ProcessCommand();	// Check for incoming USB serial commands
		config.SaveConfig();		// Save any scheduled changes
		calib.Calibrate();			// Calibration state machine
		additive.IdleJobs();		// Calculate levels of sine wave multipliers

#if (USB_DEBUG)
		if ((GPIOB->IDR & GPIO_IDR_ID4) == 0 && USBDebug) {
			USBDebug = false;
			usb.OutputDebug();
		}
#endif

	}
}

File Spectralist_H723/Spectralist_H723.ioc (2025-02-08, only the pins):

Mcu.UserName=STM32H723VGTx
PA0.Signal=ADC1_INP16
PA1.Signal=ADC1_INP17
PA11.Signal=USB_OTG_HS_DM
PA12.Signal=USB_OTG_HS_DP
PA13(JTMS/SWDIO).Signal=DEBUG_JTMS-SWDIO
PA14(JTCK/SWCLK).Signal=DEBUG_JTCK-SWCLK
PA15(JTDI).Signal=SPI3_NSS
PA2.Signal=ADCx_INP14
PA3.Signal=ADCx_INP15
PA4.Signal=ADCx_INP18
PA5.Signal=ADCx_INP19
PA6.Signal=ADCx_INP3
PA7.Signal=ADCx_INP7
PA9.Signal=USB_OTG_HS_VBUS
PB0.Signal=ADCx_INP9
PB1.Signal=ADCx_INP5
PB12.Signal=I2S2_WS
PB13.Signal=I2S2_CK
PB15.Signal=I2S2_SDO
PC0.Signal=ADCx_INP10
PC1.Signal=ADCx_INP11
PC10.Signal=I2C5_SDA
PC11.Signal=I2C5_SCL
PC2_C.Signal=ADC3_INP0
PC4.Signal=ADCx_INP4
PC5.Signal=ADCx_INP8
PD13.Signal=S_TIM4_CH2
PD14.GPIO_Label=Octave_LED_Output
PD14.Signal=GPIO_Output
PD15.Signal=S_TIM4_CH4
PD5.Signal=USART2_TX
PD6.Signal=USART2_RX
PE2.Signal=GPIO_Input
PE3.Signal=GPIO_Input
PE4.Signal=GPIO_Input
PH0-OSC_IN.Signal=RCC_OSC_IN
PH1-OSC_OUT.Signal=RCC_OSC_OUT

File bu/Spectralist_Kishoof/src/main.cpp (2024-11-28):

#include "initialisation.h"
#include "CDCHandler.h"
#include "USB.h"
#include "WaveTable.h"
#include "configManager.h"
#include "Calib.h"
#include "Filter.h"
#include "lcd.h"
#include "ExtFlash.h"
#include "UI.h"
#include "Additive.h"

bool modeSpectralist = false;
volatile uint32_t SysTickVal;
extern uint32_t SystemCoreClock;
bool SafeMode = false;				// Disables file system mounting, USB MSC drive is disabled, don't load config

volatile ADCValues __attribute__((section (".dma_buffer"))) adc;	// Store adc buffer in non-cached memory area

Config config{&wavetable.configSaver, &calib.configSaver, &ui.configSaver};		// Construct config handler with list of configSavers

extern "C" {
#include "interrupts.h"
}

bool USBDebug = false;

int main(void) {

	InitClocks();					// Configure the clock and PLL
	InitHardware();

	if (GpioPin::IsLow(GPIOE, 4)) {	// If encoder button is pressed enter 'safe-mode'
		SafeMode = true;
	}

	lcd.Init();
	extFlash.Init();
	filter.Init();					// Initialise look up table of filter coefficients, windows etc
	if (!SafeMode) {
		config.RestoreConfig();
	}
	wavetable.Init();
	usb.Init(false);
	InitI2S();						// Initialise I2S which will start main sample interrupts

	while (1) {
		usb.cdc.ProcessCommand();	// Check for incoming USB serial commands
		ui.Update();
		fatTools.CheckCache();		// Check if any outstanding cache changes need to be written to Flash
		config.SaveConfig();		// Save any scheduled changes
		CheckVCA();					// Bodge to check if VCA is normalled to 3.3v
		calib.Calibrate();
		if (modeSpectralist) {
			additive.IdleJobs();
		}
#if (USB_DEBUG)
		if ((GPIOB->IDR & GPIO_IDR_ID4) == 0 && USBDebug) {
			USBDebug = false;
			usb.OutputDebug();
		}
#endif

	}
}

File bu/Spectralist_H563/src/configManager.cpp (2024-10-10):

#include "configManager.h"
#include <cstring>
#include <cstdio>
#include <algorithm>

bool Config::SaveConfig(const bool forceSave)
{
	bool result = true;
	if (forceSave || (scheduleSave && SysTickVal > saveBooked + 60000)) {			// 60 seconds between saves
		GpioPin::SetHigh(GPIOD, 5);
		scheduleSave = false;

		if (currentSettingsOffset == -1) {					// Default = -1 if not first set in RestoreConfig
			currentSettingsOffset = 0;
		} else {
			currentSettingsOffset += settingsSize;
			if ((uint32_t)currentSettingsOffset > flashSectorSize - settingsSize) {
				// Check if another sector is available for use
				for (auto& sector : sectors) {
					if (!sector.dirty && sector.sector != currentSector) {
						if (++currentIndex > configSectorCount) { 	// set new index, wrapping at count of allowed config sectors
							currentIndex = 0;
						}
						currentSector = sector.sector;
						SetCurrentConfigAddr();
						currentSettingsOffset = 0;
						sector.index = currentIndex;
						sector.dirty = true;
						break;
					}
				}
				if (currentSettingsOffset != 0) {				// No free configurations slots found - abort save
					printf("Error saving config - no space\r\n");
					return false;
				}
			}
		}
		uint32_t* flashPos = flashConfigAddr + currentSettingsOffset / 4;


		uint8_t configBuffer[settingsSize];					// Will hold all the data to be written by config savers
		memcpy(configBuffer, ConfigHeader, 4);
		configBuffer[4] = currentIndex;						// Store the index of the config to identify the active sector
		uint32_t configPos = headerSize;
		for (auto& saver : configSavers) {					// Add individual config settings to buffer after header
			memcpy(&configBuffer[configPos], saver->settingsAddress, saver->settingsSize);
			configPos += saver->settingsSize;
		}

		FlashUnlock();										// Unlock Flash memory for writing
		FLASH->NSCCR = flashAllErrors;						// Clear error flags in Status Register
		result = FlashProgram(flashPos, reinterpret_cast<uint32_t*>(&configBuffer), settingsSize);
		FlashLock();										// Lock Flash

		if (result) {
			printf("Config Saved (%lu bytes at %#010lx)\r\n", settingsSize, (uint32_t)flashPos);
		} else {
			printf("Error saving config\r\n");
		}
		GpioPin::SetLow(GPIOD, 5);
	}
	return result;
}


void Config::RestoreConfig()
{
	// Initialise sector array - used to manage which sector contains current config, and which sectors are available for writing when current sector full
	for (uint32_t i = 0; i < configSectorCount; ++i) {
		sectors[i].sector = flashConfigSector + i;
		uint32_t* const addr = flashConfigAddr + i * (flashSectorSize / 4);

		// Check if sector is dirty
		for (uint32_t w = 0; w < (flashSectorSize / 4); ++w) {
			if (addr[w] != 0xFFFFFFFF) {
				sectors[i].dirty = true;
				break;
			}
		}

		// Check if there is a config block at the start of the sector and read the index number if so
		sectors[i].index = (addr[0] == *(uint32_t*)ConfigHeader) ? (uint8_t)addr[1] : 255;
	}

	// Work out which is the active config sector: will be the highest index from the bottom before the sequence jumps
	std::sort(sectors.begin(), sectors.end(), [](const CfgSector& l, const CfgSector& r) { return l.index < r.index; });
	uint32_t index = sectors[0].index;
	if (index == 255) {
		currentSector = flashConfigSector;
		currentIndex = 0;					// Each sector is assigned an index to determine which contains the latest config
	} else {
		currentSector = sectors[0].sector;
		for (uint32_t i = 1; i < configSectorCount; ++i) {
			if (sectors[i].index == index + 1) {
				++index;
				currentSector = sectors[i].sector;
			} else {
				break;
			}
		}
		currentIndex = index;
	}
	SetCurrentConfigAddr();				// Set the base address of the sector holding the current config

	// Erase any dirty sectors that are not the current one, or do not contain config data
	for (auto& sector : sectors) {
		if (sector.dirty && (sector.sector != currentSector || sector.index == 255)) {
			FlashEraseSector(sector.sector);
			sector.index = 255;
			sector.dirty = false;
		}
	}
	std::sort(sectors.begin(), sectors.end(), [](const CfgSector& l, const CfgSector& r) { return l.sector < r.sector; });

	// Locate latest (active) config block
	uint32_t pos = 0;
	while (pos <= flashSectorSize - settingsSize) {
		if (*(flashConfigAddr + pos / 4) == *(uint32_t*)ConfigHeader) {
			currentSettingsOffset = pos;
			pos += settingsSize;
		} else {
			break;			// Either reached the end of the sector or found the latest valid config block
		}
	}

	if (currentSettingsOffset >= 0) {
		const uint8_t* flashConfig = reinterpret_cast<uint8_t*>(flashConfigAddr) + currentSettingsOffset;
		uint32_t configPos = headerSize;		// Position in buffer to retrieve settings from

		// Restore settings
		for (auto saver : configSavers) {
			memcpy(saver->settingsAddress, &flashConfig[configPos], saver->settingsSize);
			if (saver->validateSettings != nullptr) {
				saver->validateSettings();
			}
			configPos += saver->settingsSize;
		}
	}
}
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

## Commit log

2024-10-25 Started firmware testing using Kishoof hardware
    [mkfs.xls, mkfs.xlsx]
2024-11-17 Incorporate filtering
2024-11-23 Channel Filter controls also CV controllable
2024-11-29 Added calibration defaults
2024-12-02 Added long press function to switch mode
2024-12-06 Added comb filter mode
2024-12-07 Changed comb filter from repeating notches to comb
    Fixed bug in graphics
    Fixed issues with filter calculations being skipped
    [Additive.cpp]
2024-12-07 Reverse LPF filter slope control and make exponential
    [Additive.cpp]
2024-12-08 Started adding schematic; fix to cosine spread calculation
    [Spectralist_Components.kicad_pcb, Spectralist_Components.kicad_sch]
2024-12-08 Attenuate last two harmonics to avoid glitching
    [Additive.cpp]
2024-12-12 Rough first draft of panel layout
    [Spectralist_Panel.kicad_pcb]
2024-12-16 Schematic updates
    [Spectralist_Components.kicad_pcb, Spectralist_Components.kicad_sch, Spectralist_LEDs.kicad_pcb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]
2024-12-18 Updates to LED board
    [Spectralist_Controls.kicad_pcb, Spectralist_Controls.kicad_sch, Spectralist_LEDs.kicad_pcb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]
2024-12-20 Curvy traces on LED board
    [Spectralist_Components.kicad_sch, Spectralist_Controls.kicad_pcb, Spectralist_Controls.kicad_sch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]
2024-12-22 Component PCB updates
    [Spectralist_Components.kicad_pcb, Spectralist_Components.kicad_sch, Spectralist_Controls.kicad_pcb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]
2024-12-24 Started adding USB
    [Spectralist_Components.kicad_pcb, Spectralist_Components.kicad_sch]
2025-01-07 More layout on Component and Control boards
    [Spectralist_Components.kicad_pcb, Spectralist_Components.kicad_sch, Spectralist_Controls.kicad_pcb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]
2025-01-08 More PCB Layout
    [Spectralist_Components.kicad_pcb, Spectralist_Components.kicad_sch, Spectralist_Controls.kicad_pcb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]
2025-01-15 Started adding JLC part numbers
    [BOM-Spectralist_Components.csv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]
2025-01-18 v1.0 PCBs sent to production
    [BOM-Spectralist_Components.csv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]
2025-01-29 Started bring up of v1 production board
    [Spectralist_Components.kicad_sch]
2025-02-01 Hardware fixes
    [Spectralist_Controls.kicad_sch]
2025-02-02 Implemented Filter LEDs and Octave down button/LED
    [Spectralist_Controls.kicad_sch]
2025-02-04 Switching to 15 bit sine LUT in DTCMRAM for big performance boost
2025-02-06 Code tidy up; implementing CV , pots and trimmers
    [Spectralist_Components.kicad_pcb, Spectralist_Components.kicad_sch, Spectralist_Controls.kicad_pcb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]
2025-02-07 Filter slope fixes
2025-02-08 Started I2C code
2025-02-17 LED I2C Chip programmable via USB console
    [Spectralist_LEDs.kicad_sch]
2025-02-18 LED DMA working
2025-02-20 Added dynamic LED display
    Shows a stylised representation of stretch and warp settings
    [Additive.cpp, ledManager.cpp]
2025-02-20 Updated panel with correct sub-miniature switch hole size
    [Spectralist_Components.kicad_sch, Spectralist_Panel.kicad_pcb]
2025-02-21 Correction to calibration
2025-02-26 Code Clean up
    [Spectralist_Components.kicad_sch]
2025-03-25 Added readme
    [Spectralist_Components.kicad_sch, mkfs.xls, mkfs.xlsx]
